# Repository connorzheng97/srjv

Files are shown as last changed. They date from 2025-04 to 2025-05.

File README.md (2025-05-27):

# srjv
SR-JV80 Programmable Expansion Card with ESP32 Wi-Fi
- Product info page at https://www.ddzheng.cc/?page_id=666
- Blog post at https://www.ddzheng.cc/?p=617

This board is a re-writable ROM card with a Wi-Fi based user interface. It can store a ROM image up to 8MB/64Mbit, usually custom authored, and be used in compatible Roland synthesizers in place of an original SR-JV80 series expansion card to research the sound generation and synthesizing.

SR-JV80 Wi-Fi Board

# Hardware Info
- ESP32-S3 Wroom module requires at least 2 MB Flash (No OTA) or 4 MB (with OTA).
- The NOR flash can be TSSOP 48 or 56 pin, 8 MB or more, 70ns or faster, with byte (8-bit) mode support. Regularly used for production is MX29LV640
- Connector is 40 pin SCSI all plastic connector or similar. The original card use MOLEX 52326-0401
- Reverse taped LED is only required for SMT production. For hand assembling regular 1206 LED can be used.

# Fabricating
4-layer board. Can also be made with 2 layers without modification. Assemble as indicated (DNP = do not populate) in schematic.

# Licsensing

Copyright Connor Zheng 2025.

This source describes Open Hardware and is licensed under the CERN-OHLW v2 or later. You may redistribute and modify this documentation and make products using it under the terms of the CERN-OHL-W v2 [https:/cern.ch/cern-ohl](https:/cern.ch/cern-ohl). This documentation is distributed WITHOUT ANY EXPRESS OR IMPLIED WARRANTY, INCLUDING OF MERCHANTABILITY, SATISFACTORY QUALITY AND FITNESS FOR A PARTICULAR PURPOSE. Please see the CERN-OHL-W v2 for applicable conditions.

Source location: [https://github.com/connorzheng97/srjv](https://github.com/connorzheng97/srjv)

As per CERN-OHL-W v2 section 4.1, should You produce hardware based on these sources, You must maintain the Source Location visible on the external case and PCB top layer silkscreen of the SRJV or other product you make using this documentation.

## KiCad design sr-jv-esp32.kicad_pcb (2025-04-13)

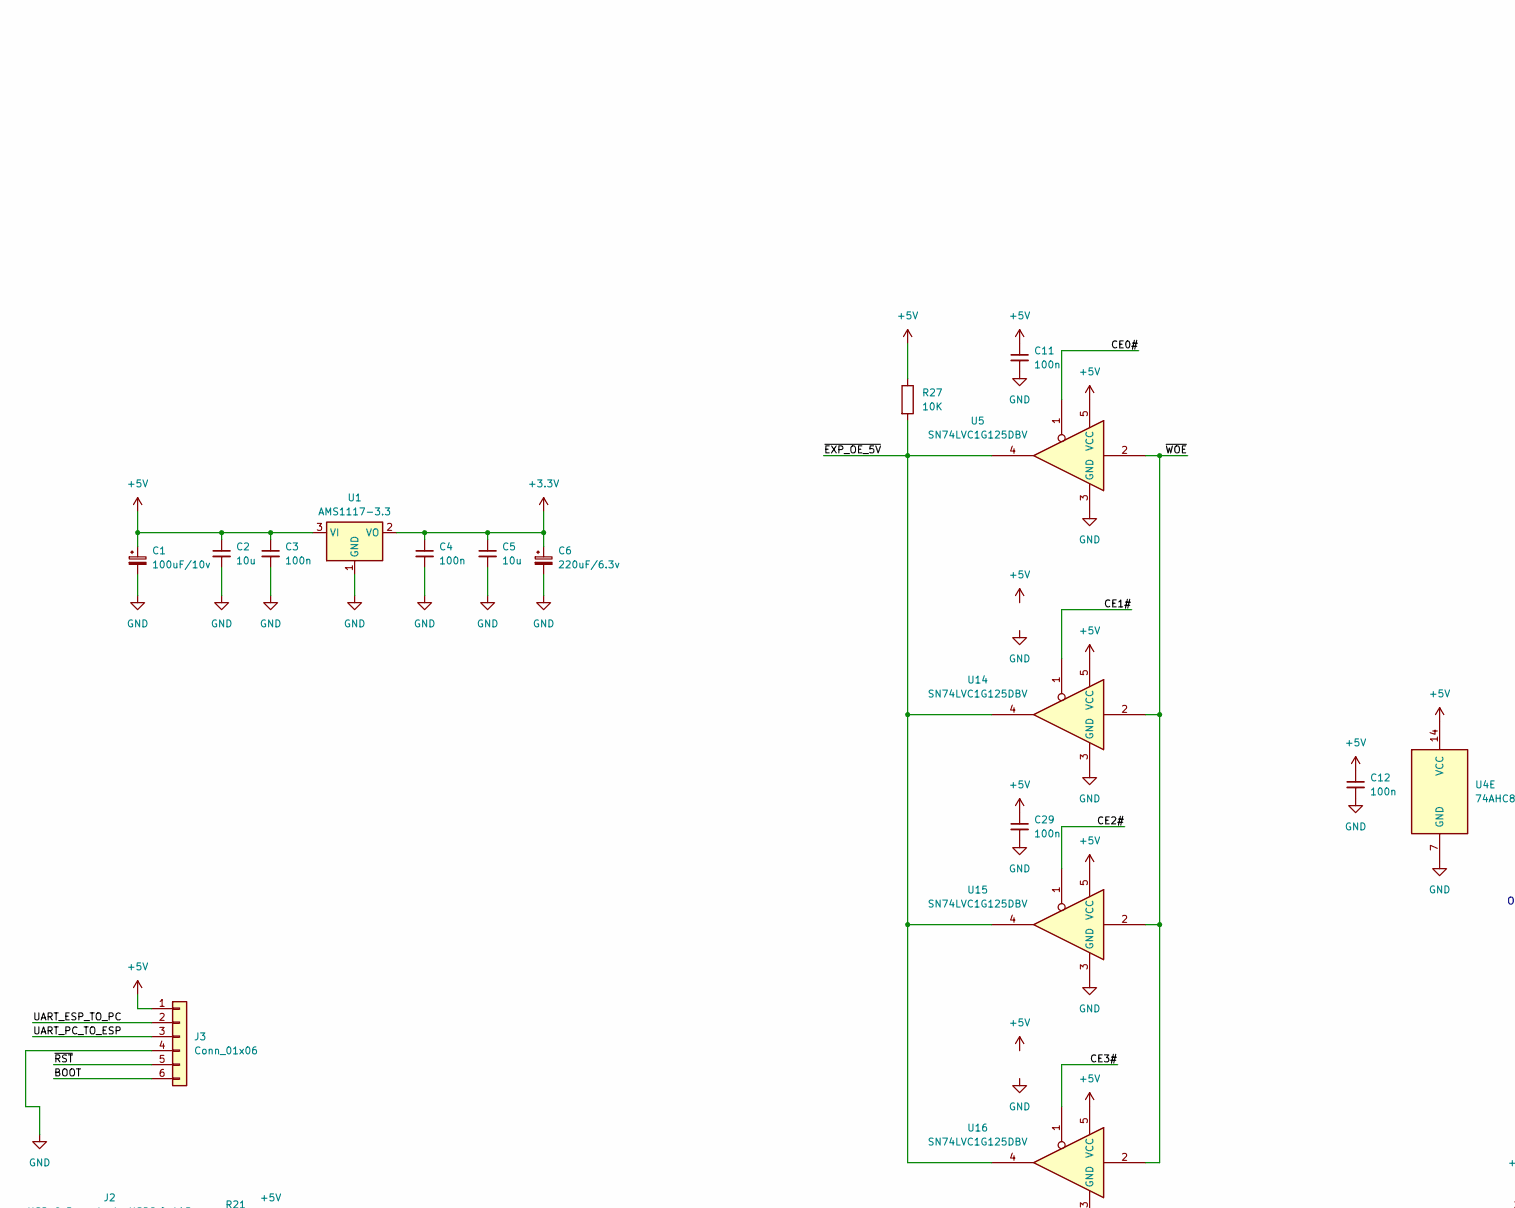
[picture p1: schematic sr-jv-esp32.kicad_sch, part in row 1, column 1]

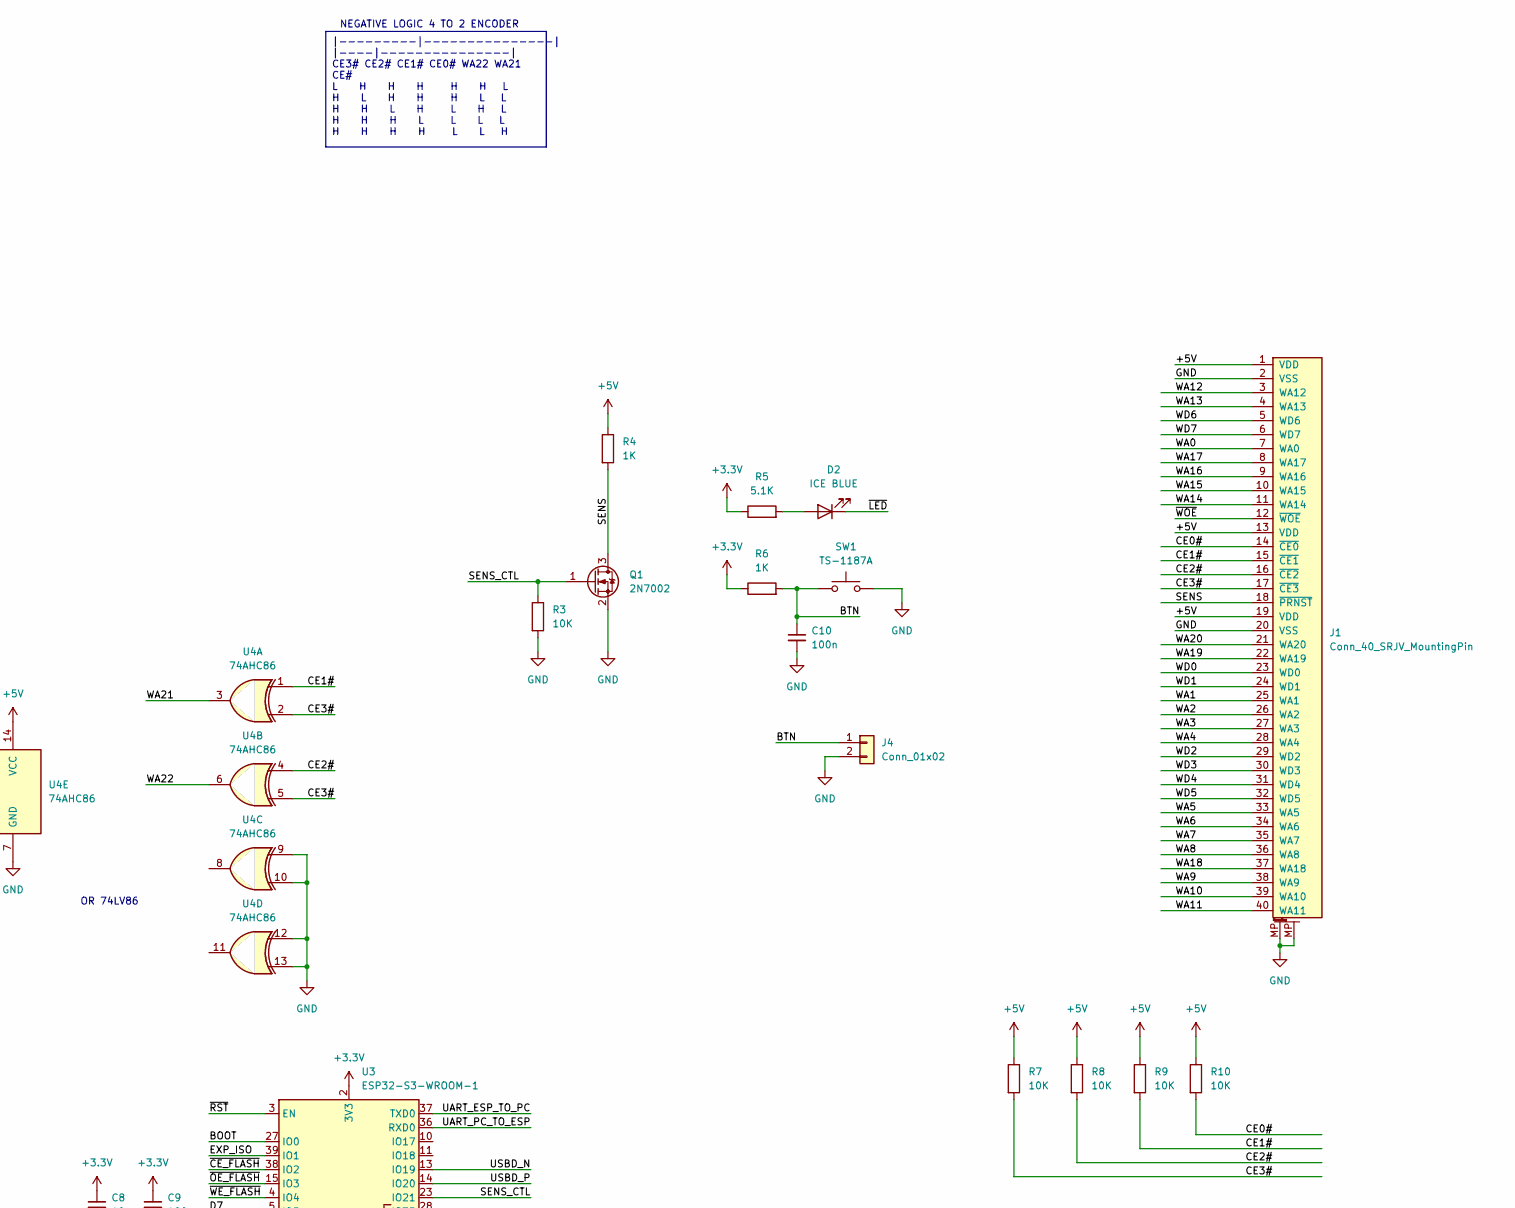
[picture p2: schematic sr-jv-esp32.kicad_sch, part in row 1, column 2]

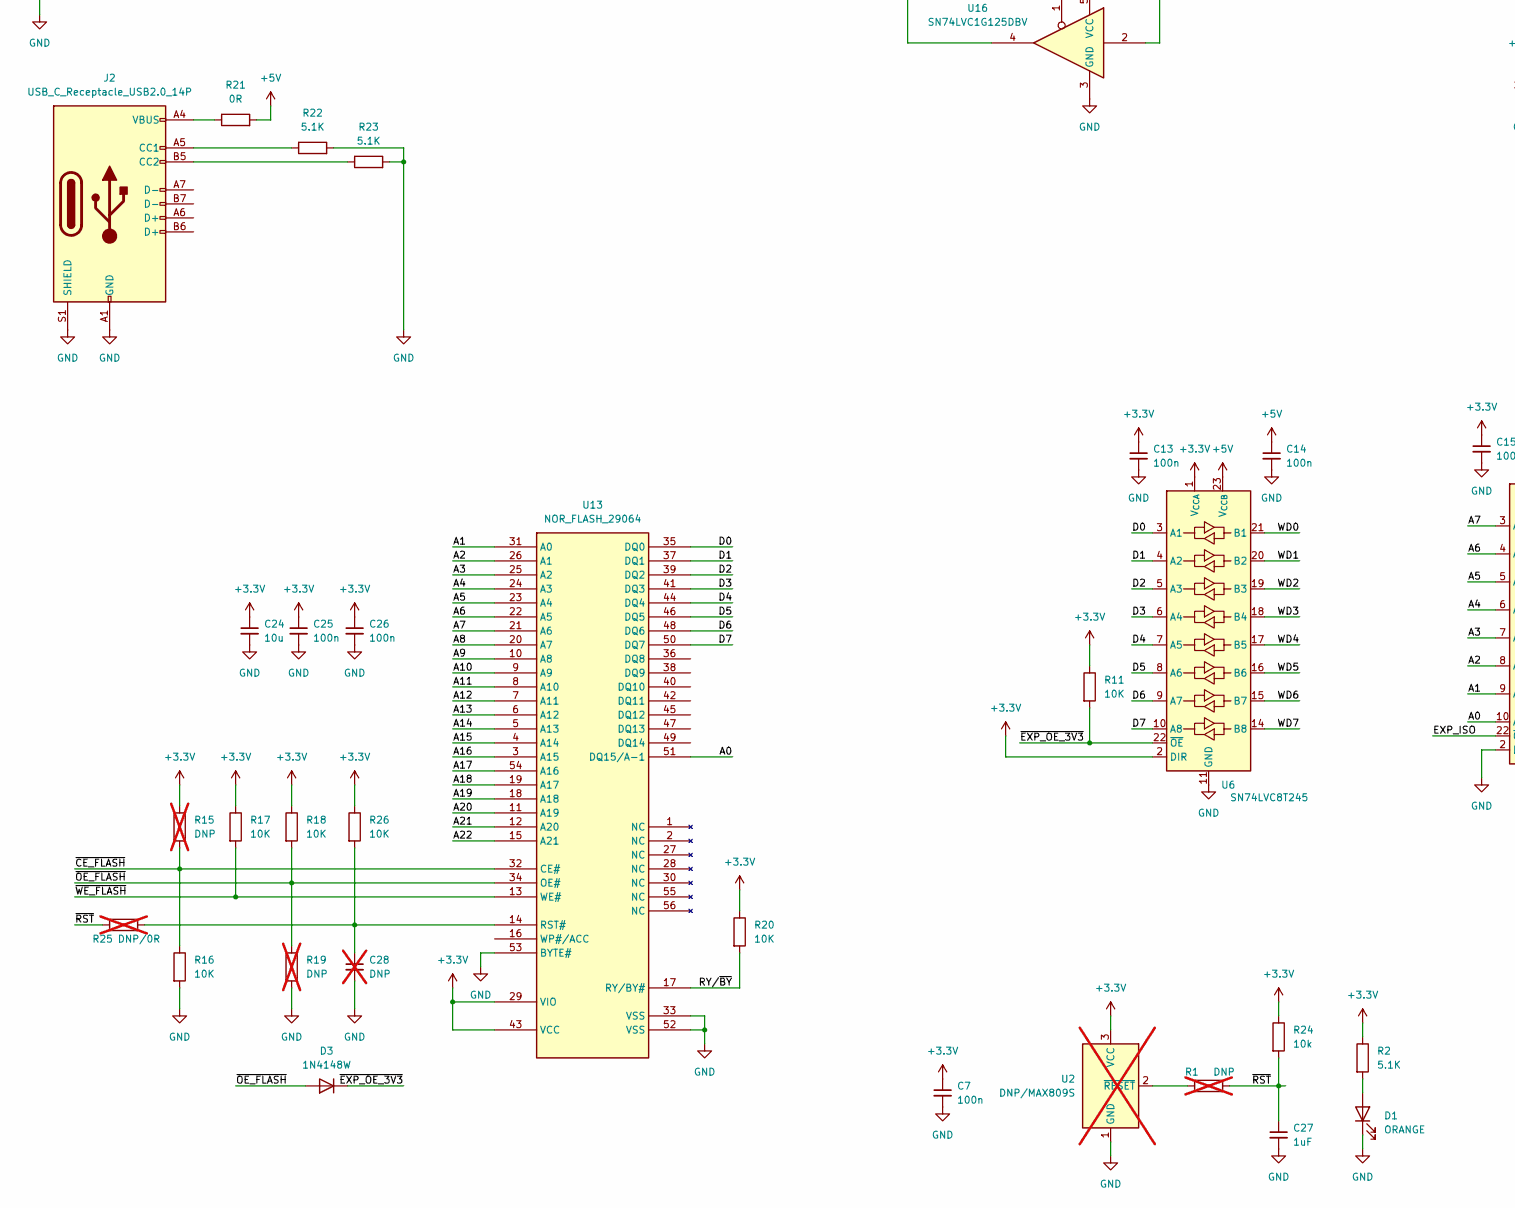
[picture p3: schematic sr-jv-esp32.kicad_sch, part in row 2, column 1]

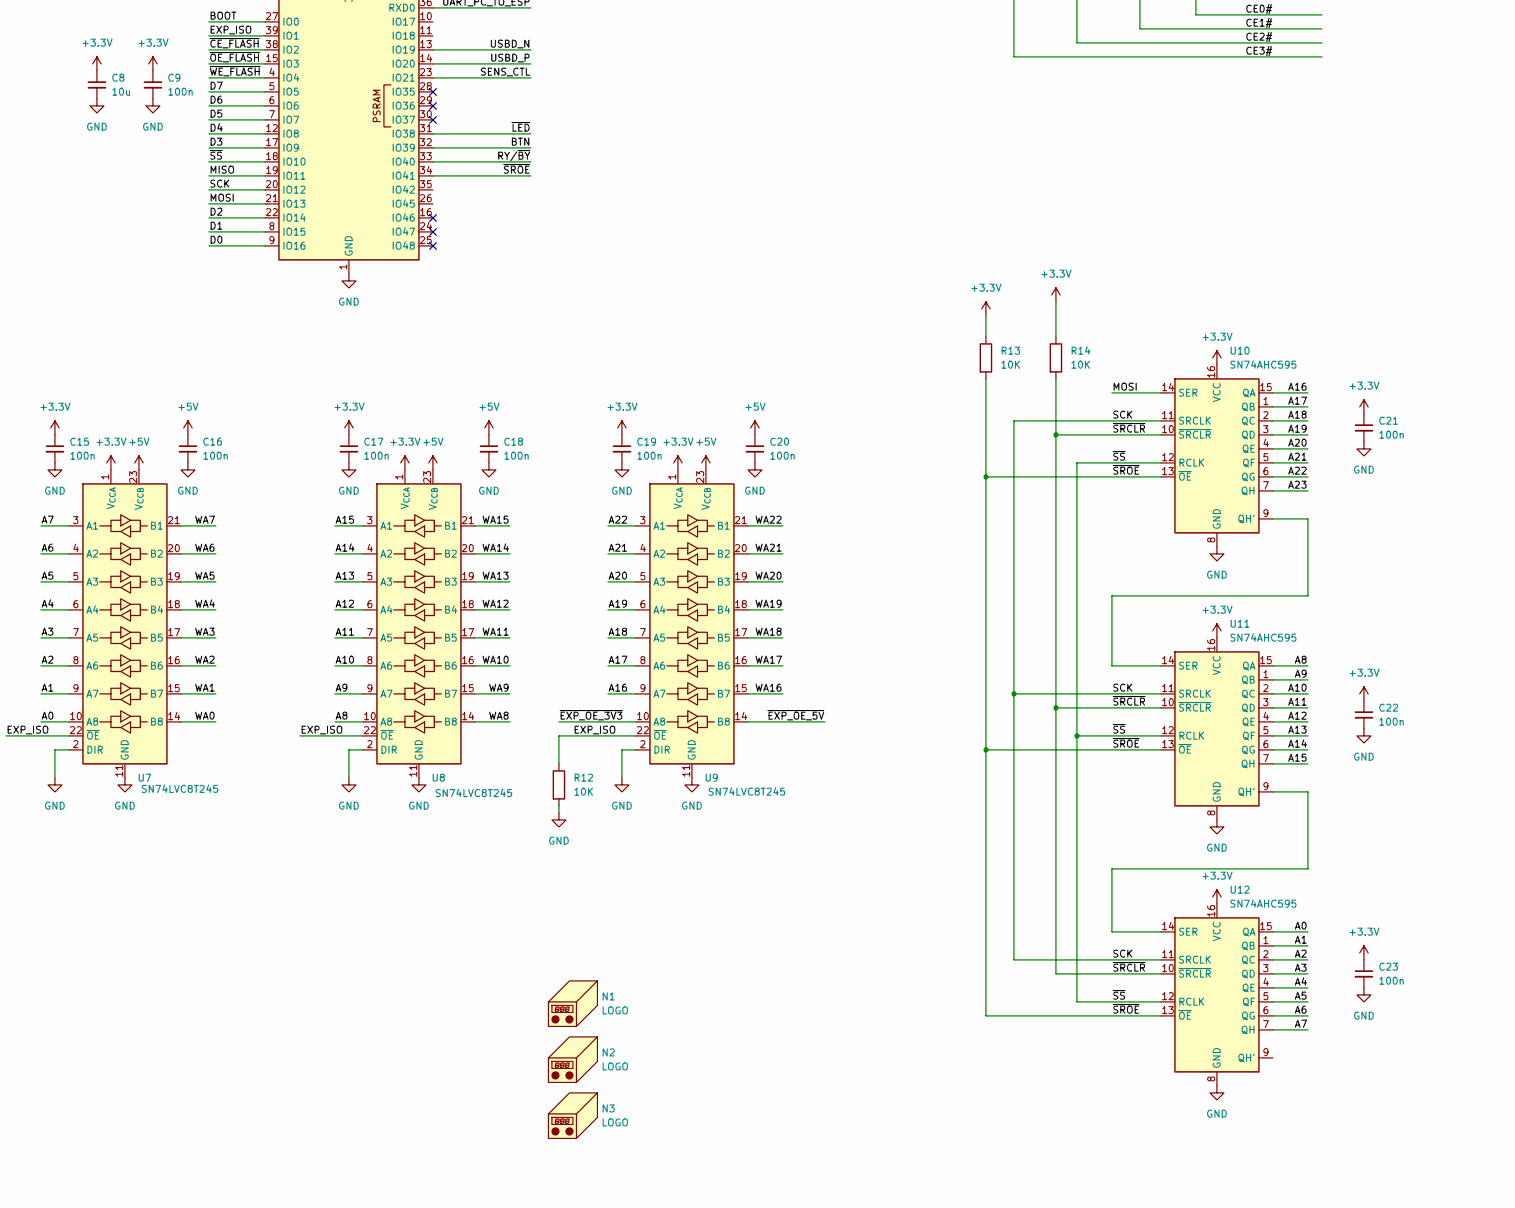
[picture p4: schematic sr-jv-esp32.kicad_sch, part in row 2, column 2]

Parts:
C1: 100uF/10v; CP_Radial_D6.3mm_P2.50mm
C2, C5, C8, C24: 10u; C_0603_1608Metric
C3, C4, C7, C9, C10, C11, C12, C13, C14, C15, C16, C17, C18, C19, C20, C21, C22, C23, C25, C26, C29: 100n; C_0603_1608Metric
C6: 220uF/6.3v; CP_Radial_D6.3mm_P2.50mm
C27: 1uF; C_0603_1608Metric
C28: DNP; C_0603_1608Metric; not fitted
D1: ORANGE; LED_1206_3216Metric_ReverseMount
D2: ICE BLUE; LED_1206_3216Metric_ReverseMount
D3: 1N4148W; D_SOD-123
J1: Conn_40_SRJV_MountingPin; CONN_40P_SCSI_THT_Vertical
J2: USB_C_Receptacle_USB2.0_14P; USB_C_Receptacle_GCT_USB4105-xx-A_16P_TopMnt_Horizontal
J3: Conn_01x06; PinHeader_1x06_P2.54mm_Vertical
J4: Conn_01x02; JST_XH_B2B-XH-A_1x02_P2.50mm_Vertical
N1: LOGO; OSHW-Logo_5.7x6mm_SilkScreen
N2: LOGO; ESD-Logo_6.6x6mm_SilkScreen
N3: LOGO; WEEE-Logo_5.6x8mm_SilkScreen
Q1: 2N7002; SOT-23
R1, R15, R19: DNP; R_0603_1608Metric; not fitted
R2, R5, R22, R23: 5.1K; R_0603_1608Metric
R3, R7, R8, R9, R10, R11, R12, R13, R14, R16, R17, R18, R20, R26, R27: 10K; R_0603_1608Metric
R4, R6: 1K; R_0603_1608Metric
R21: 0R; R_0603_1608Metric
R24: 10k; R_0603_1608Metric
R25: DNP/0R; R_0603_1608Metric; not fitted
SW1: TS-1187A; SW_Push_1P1T_XKB_TS-1187A_LONGPAD
U1: AMS1117-3.3; SOT-223-3_TabPin2
U2: DNP/MAX809S; SOT-23; not fitted
U3: ESP32-S3-WROOM-1
U4: 74AHC86; TSSOP-14_4.4x5mm_P0.65mm
U5, U14, U15, U16: SN74LVC1G125DBV; SOT-23-5
U6, U7, U8, U9: SN74LVC8T245; TSSOP-24_4.4x7.8mm_P0.65mm
U10, U11, U12: SN74AHC595; TSSOP-16_4.4x5mm_P0.65mm
U13: NOR_FLASH_29064; TSOP-I-56_48_18.4x14mm_P0.5mm

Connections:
+3.3V: C4.1, C5.1, C6.1, C7.1, C8.1, C9.1, C13.1, C15.1, C17.1, C19.1, C21.1, C22.1, C23.1, C24.1, C25.1, C26.1, R2.1, R5.1, R6.1, R11.1, R13.1, R14.1, R15.1, R17.1, R18.1, R20.1, R24.1, R26.1, U1.2 (VO), U2.3 (VCC), U3.2 (3V3), U6.1 (V_{CCA}), U6.2 (DIR), U7.1 (V_{CCA}), U8.1 (V_{CCA}), U9.1 (V_{CCA}), U10.16 (VCC), U11.16 (VCC), U12.16 (VCC), U13.29 (VIO), U13.43 (VCC)
+5V: C1.1, C2.1, C3.1, C11.1, C12.1, C14.1, C16.1, C18.1, C20.1, C29.1, J1.1 (VDD), J1.13 (VDD), J1.19 (VDD), J3.1, R4.1, R7.1, R8.1, R9.1, R10.1, R21.2, R27.1, U1.3 (VI), U4.14 (VCC), U5.5 (VCC), U6.23 (V_{CCB}), U6.24 (V_{CCB}), U7.23 (V_{CCB}), U7.24 (V_{CCB}), U8.23 (V_{CCB}), U8.24 (V_{CCB}), U9.23 (V_{CCB}), U9.24 (V_{CCB}), U14.5 (VCC), U15.5 (VCC), U16.5 (VCC)
/A0: U7.10 (A8), U12.15 (QA), U13.51 (DQ15/A-1)
/A1: U7.9 (A7), U12.1 (QB), U13.31 (A0)
/A2: U7.8 (A6), U12.2 (QC), U13.26 (A1)
/A3: U7.7 (A5), U12.3 (QD), U13.25 (A2)
/A4: U7.6 (A4), U12.4 (QE), U13.24 (A3)
/A5: U7.5 (A3), U12.5 (QF), U13.23 (A4)
/A6: U7.4 (A2), U12.6 (QG), U13.22 (A5)
/A7: U7.3 (A1), U12.7 (QH), U13.21 (A6)
/A8: U8.10 (A8), U11.15 (QA), U13.20 (A7)
/A9: U8.9 (A7), U11.1 (QB), U13.10 (A8)
/A10: U8.8 (A6), U11.2 (QC), U13.9 (A9)
/A11: U8.7 (A5), U11.3 (QD), U13.8 (A10)
/A12: U8.6 (A4), U11.4 (QE), U13.7 (A11)
/A13: U8.5 (A3), U11.5 (QF), U13.6 (A12)
/A14: U8.4 (A2), U11.6 (QG), U13.5 (A13)
/A15: U8.3 (A1), U11.7 (QH), U13.4 (A14)
/A16: U9.9 (A7), U10.15 (QA), U13.3 (A15)
/A17: U9.8 (A6), U10.1 (QB), U13.54 (A16)
/A18: U9.7 (A5), U10.2 (QC), U13.19 (A17)
/A19: U9.6 (A4), U10.3 (QD), U13.18 (A18)
/A20: U9.5 (A3), U10.4 (QE), U13.11 (A19)
/A21: U9.4 (A2), U10.5 (QF), U13.12 (A20)
/A22: U9.3 (A1), U10.6 (QG), U13.15 (A21)
/A23: U10.7 (QH)
/BOOT: J3.6, U3.27 (IO0)
/BTN: C10.1, J4.1, R6.2, SW1.1, U3.32 (IO39)
/CE0#: J1.14 (~CE0), R10.2, U5.1
/CE1#: J1.15 (~CE1), R9.2, U4.1, U14.1
/CE2#: J1.16 (~CE2), R8.2, U4.4, U15.1
/CE3#: J1.17 (~CE3), R7.2, U4.2, U4.5, U16.1
/D0: U3.9 (IO16), U6.3 (A1), U13.35 (DQ0)
/D1: U3.8 (IO15), U6.4 (A2), U13.37 (DQ1)
/D2: U3.22 (IO14), U6.5 (A3), U13.39 (DQ2)
/D3: U3.17 (IO9), U6.6 (A4), U13.41 (DQ3)
/D4: U3.12 (IO8), U6.7 (A5), U13.44 (DQ4)
/D5: U3.7 (IO7), U6.8 (A6), U13.46 (DQ5)
/D6: U3.6 (IO6), U6.9 (A7), U13.48 (DQ6)
/D7: U3.5 (IO5), U6.10 (A8), U13.50 (DQ7)
/EXP_ISO: R12.1, U3.39 (IO1), U7.22 (~OE), U8.22 (~OE), U9.22 (~OE)
/MISO: U3.19 (IO11)
/MOSI: U3.21 (IO13), U10.14 (SER)
/RY/~BY: R20.2, U3.33 (IO40), U13.17 (RY/BY#)
/SCK: U3.20 (IO12), U10.11 (SRCLK), U11.11 (SRCLK), U12.11 (SRCLK)
/SENS: J1.18 (~PRNST), Q1.3 (D), R4.2
/SENS_CTL: Q1.1 (G), R3.1, U3.23 (IO21)
/UART_ESP_TO_PC: J3.2, U3.37 (TXD0)
/UART_PC_TO_ESP: J3.3, U3.36 (RXD0)
/USBD_N: U3.13 (IO19)
/USBD_P: U3.14 (IO20)
/WA0: J1.7 (WA0), U7.14 (B8)
/WA1: J1.25 (WA1), U7.15 (B7)
/WA2: J1.26 (WA2), U7.16 (B6)
/WA3: J1.27 (WA3), U7.17 (B5)
/WA4: J1.28 (WA4), U7.18 (B4)
/WA5: J1.33 (WA5), U7.19 (B3)
/WA6: J1.34 (WA6), U7.20 (B2)
/WA7: J1.35 (WA7), U7.21 (B1)
/WA8: J1.36 (WA8), U8.14 (B8)
/WA9: J1.38 (WA9), U8.15 (B7)
/WA10: J1.39 (WA10), U8.16 (B6)
/WA11: J1.40 (WA11), U8.17 (B5)
/WA12: J1.3 (WA12), U8.18 (B4)
/WA13: J1.4 (WA13), U8.19 (B3)
/WA14: J1.11 (WA14), U8.20 (B2)
/WA15: J1.10 (WA15), U8.21 (B1)
/WA16: J1.9 (WA16), U9.15 (B7)
/WA17: J1.8 (WA17), U9.16 (B6)
/WA18: J1.37 (WA18), U9.17 (B5)
/WA19: J1.22 (WA19), U9.18 (B4)
/WA20: J1.21 (WA20), U9.19 (B3)
/WA21: U4.3, U9.20 (B2)
/WA22: U4.6, U9.21 (B1)
/WD0: J1.23 (WD0), U6.21 (B1)
/WD1: J1.24 (WD1), U6.20 (B2)
/WD2: J1.29 (WD2), U6.19 (B3)
/WD3: J1.30 (WD3), U6.18 (B4)
/WD4: J1.31 (WD4), U6.17 (B5)
/WD5: J1.32 (WD5), U6.16 (B6)
/WD6: J1.5 (WD6), U6.15 (B7)
/WD7: J1.6 (WD7), U6.14 (B8)
/~CE_FLASH: R15.2, R16.1, U3.38 (IO2), U13.32 (CE#)
/~EXP_OE_3V3: D3.1 (K), R11.2, U6.22 (~OE), U9.10 (A8)
/~EXP_OE_5V: R27.2, U5.4, U9.14 (B8), U14.4, U15.4, U16.4
/~LED: D2.1 (K), U3.31 (IO38)
/~OE_FLASH: D3.2 (A), R18.2, R19.1, U3.15 (IO3), U13.34 (OE#)
/~RST: C27.1, J3.5, R1.2, R24.2, R25.1, U3.3 (EN)
/~SRCLR: R14.2, U10.10 (~SRCLR), U11.10 (~SRCLR), U12.10 (~SRCLR)
/~SROE: R13.2, U3.34 (IO41), U10.13 (~OE), U11.13 (~OE), U12.13 (~OE)
/~SS: U3.18 (IO10), U10.12 (RCLK), U11.12 (RCLK), U12.12 (RCLK)
/~WE_FLASH: R17.2, U3.4 (IO4), U13.13 (WE#)
/~WOE: J1.12 (~WOE), U5.2, U14.2, U15.2, U16.2
GND: C1.2, C2.2, C3.2, C4.2, C5.2, C6.2, C7.2, C8.2, C9.2, C10.2, C11.2, C12.2, C13.2, C14.2, C15.2, C16.2, C17.2, C18.2, C19.2, C20.2, C21.2, C22.2, C23.2, C24.2, C25.2, C26.2, C27.2, C28.2, C29.2, D1.1 (K), J1.2 (VSS), J1.20 (VSS), J1.MP, J2.A1 (GND), J2.A12 (GND), J2.B1 (GND), J2.B12 (GND), J2.S1 (SHIELD), J3.4, J4.2, Q1.2 (S), R3.2, R12.2, R16.2, R19.2, R22.2, R23.2, SW1.2, U1.1 (GND), U2.1 (GND), U3.1 (GND), U3.40 (GND), U3.41 (GND), U4.7 (GND), U4.9, U4.10, U4.12, U4.13, U5.3 (GND), U6.11 (GND), U6.12 (GND), U6.13 (GND), U7.2 (DIR), U7.11 (GND), U7.12 (GND), U7.13 (GND), U8.2 (DIR), U8.11 (GND), U8.12 (GND), U8.13 (GND), U9.2 (DIR), U9.11 (GND), U9.12 (GND), U9.13 (GND), U10.8 (GND), U11.8 (GND), U12.8 (GND), U13.33 (VSS), U13.52 (VSS), U13.53 (BYTE#), U14.3 (GND), U15.3 (GND), U16.3 (GND)
unnamed: D1.2 (A), R2.2
unnamed: D2.2 (A), R5.2
unnamed: J2.A5 (CC1), R22.1
unnamed: J2.B5 (CC2), R23.1
unnamed: J2.A4 (VBUS), J2.A9 (VBUS), J2.B4 (VBUS), J2.B9 (VBUS), R21.1
unnamed: R1.1, U2.2 (~RESET)
unnamed: U10.9 (QH'), U11.14 (SER)
unnamed: U11.9 (QH'), U12.14 (SER)
unnamed: C28.1, R25.2, R26.2, U13.14 (RST#)

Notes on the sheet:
|---------|---------------| |----|---------------| CE3# CE2# CE1# CE0# WA22 WA21 CE# L H H H H H L H L H H H L L H H L H L H L H H H L L L L H H H H L L H
NEGATIVE LOGIC 4 TO 2 ENCODER
OR 74LV86

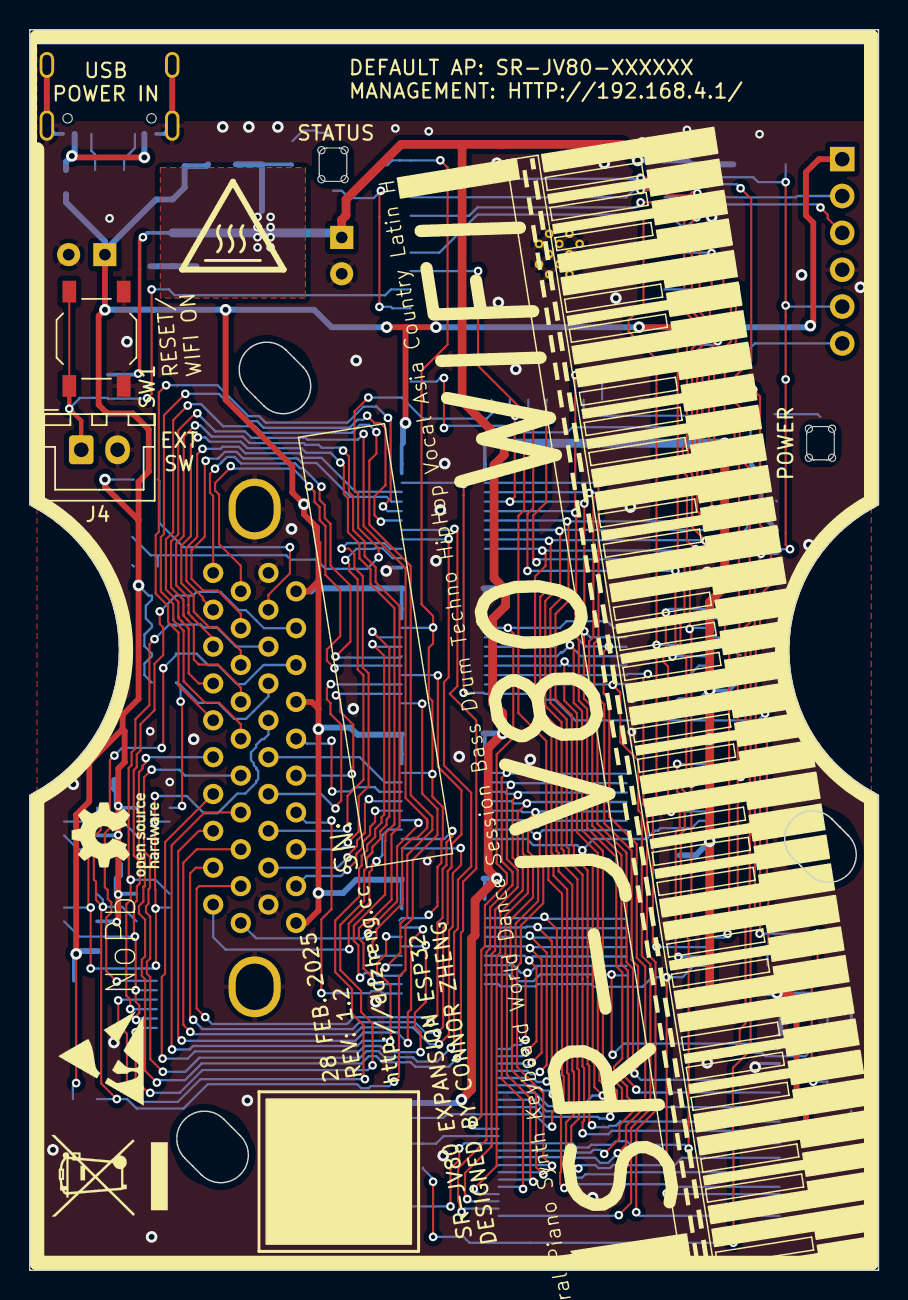
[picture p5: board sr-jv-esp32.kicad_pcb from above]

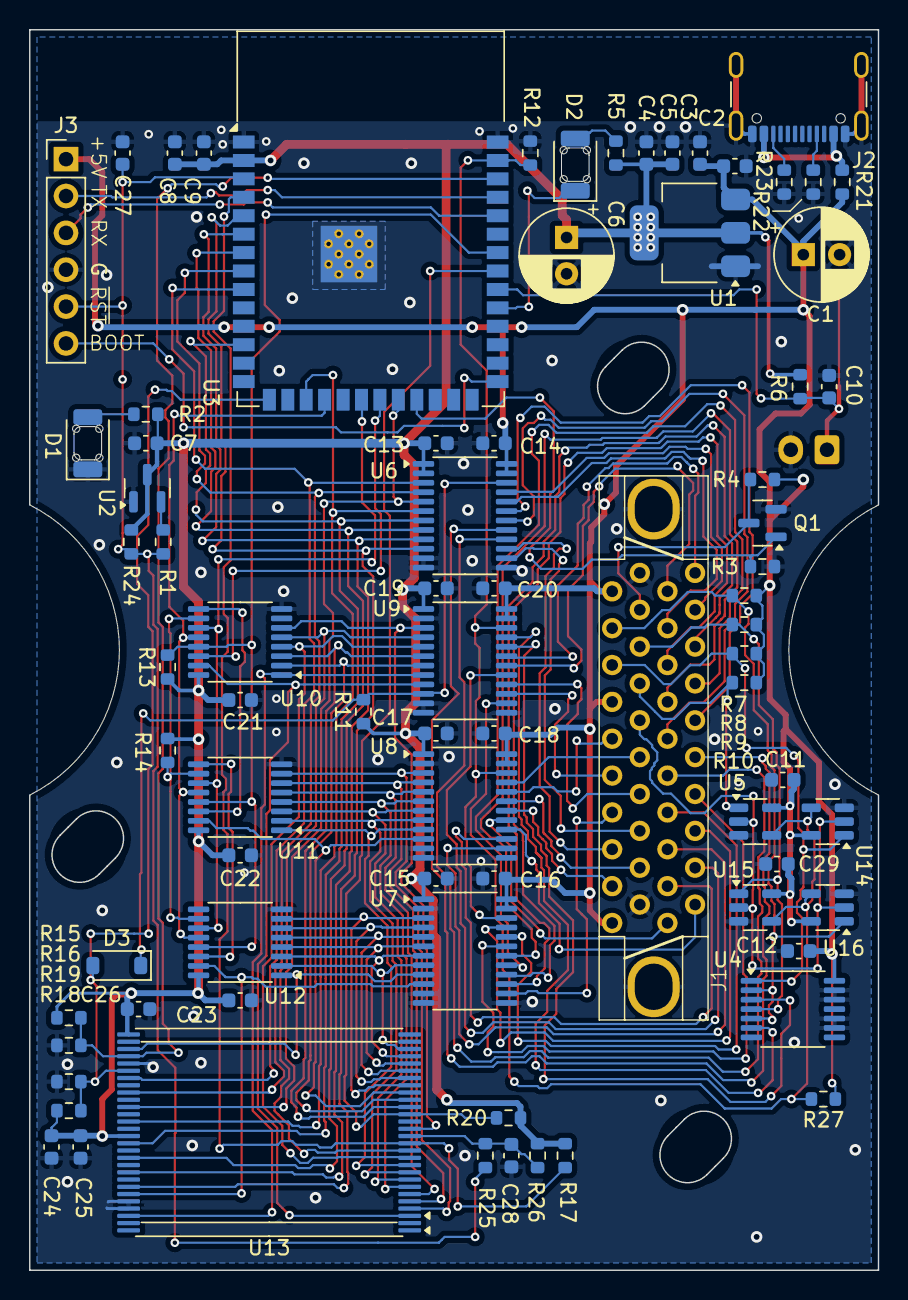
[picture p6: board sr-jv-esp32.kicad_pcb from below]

Board: 4 copper layers, 58.5 x 85.5 mm, 84 parts (79 on the bottom side), 99 nets.

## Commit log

2025-02-25 Initial commit HW Rev 1.1
    [sr-jv-esp32.kicad_pcb, sr-jv-esp32.kicad_sch]
2025-04-13 Upload MP 1.2 version
    [sr-jv-esp32.kicad_pcb, sr-jv-esp32.kicad_sch]
